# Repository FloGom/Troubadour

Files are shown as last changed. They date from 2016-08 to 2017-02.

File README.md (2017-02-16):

# Troubadour - RetroPie system
Troubadour is a [RetroPie](https://retropie.org.uk/) video game console installed in an old french TV decoder, a [Metronic Zapbox Easy 2](http://www.fnac.com/Metronic-Zapbox-Easy-2/a1663879/w-4) called MZE2 below.

**Fr**   
Troubadour est une console de jeux Rétro utilisant la distribution [RetroPie](https://retropie.org.uk/), et installée dans un ancien décodeur TNT [Metronic Zapbox Easy 2](http://www.fnac.com/Metronic-Zapbox-Easy-2/a1663879/w-4) appelé MZE2 par la suite.
Pour plus d'infos en français voir [LISEZMOI.MD](LISEZMOI.MD)

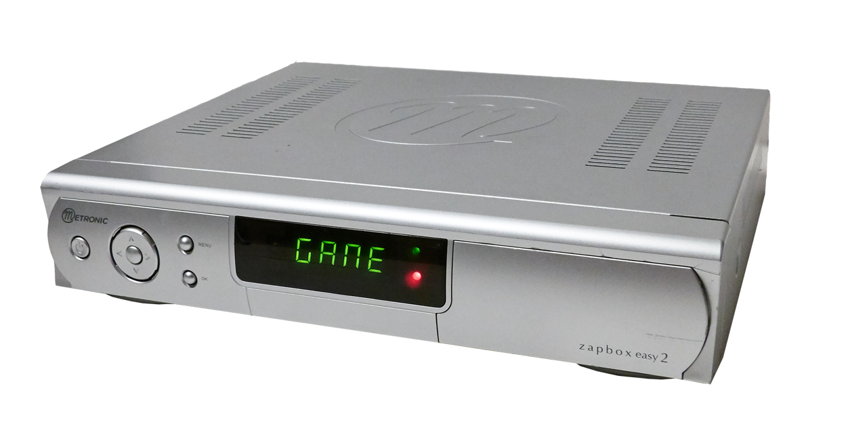
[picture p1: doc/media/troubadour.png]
troubadour


## Updates
* **2016/08/07** - Update the doc.
* **2016/08/02** - Create this repository.

## Features
* Powered with a Raspberry Pi B.
* Power supply from the old TV decoder.
* Original front panel used : volume control, display infos, shutdown button.    See [doc/usage.md](doc/usage.md) for more details.
* Most of the original connectors were used.
* USB power connector (+5V), for small speakers.
* HDMI, Composite compatible : usable on most TV.

Rear panel of Troubadour :
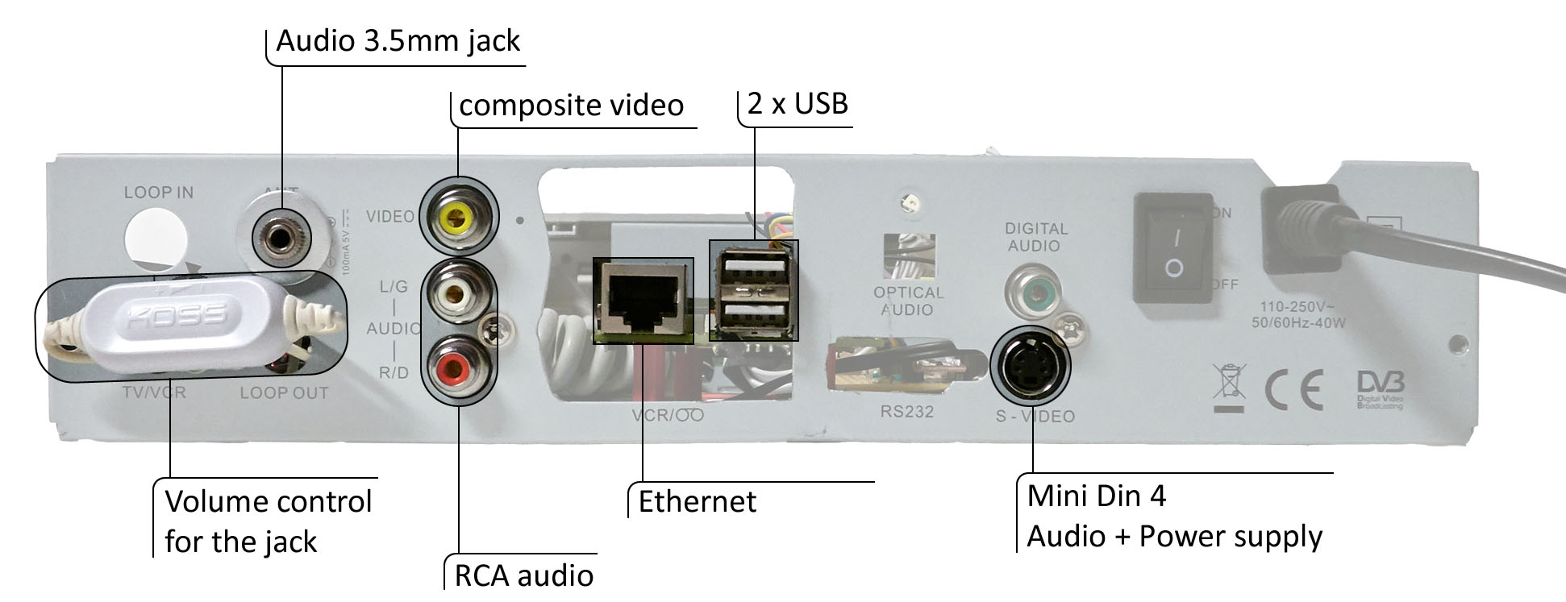
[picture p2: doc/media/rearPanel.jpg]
rear panel


## Build your own

### Internal Wiring
See [doc/wiring.md](doc/wiring.md)

### Volume control script
See [doc/vol_install.md](doc/vol_install.md)

### Build the front panel program
The program is written in C and launch on startup.   
See [doc/build.md](doc/build.md) for further details.

#### Other languages
You can find in the directory *frontPanelProg* the Arduino and python version of the code.   
I maked the Arduino version to test my comprehension of the front panel. The python version is a first attempt to control the front panel with the Raspberry Pi but python is too slow.

### Reverse engineering the front panel
See [doc/frontPanel_hack.md](doc/frontPanel_hack.md).

### Add features to the front panel
You can add more features by editing the frontPanel.c program, see [How To Program the front panel](doc/how_to_program.md) to learn how.

## License
[GNU GPL v3](LICENSE)

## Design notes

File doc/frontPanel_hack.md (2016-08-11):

# Reverse Engineering the front panel

If you want to code new messages or new features for the front panel whithout knowing precisely its design, go to [How To Program the front panel](how_to_program.md)

The front panel can be detached from the case. Using a multimeter and datasheets 
I was able to reverse engineering the front panel :)

You can find the schematics and pinouts [here](../schematics). 
They are made with [Fritzing](http://fritzing.org/home/).

## 1. Wiring of the front panel

### a. The 4 digits, 7-segments display
With the schematics, we can think about the way it works. 
As you can see on the schematics, the polarity is reverse :
* the transistors used are PNP, I made a reminder of their funcioning in the lower left corner for myself. Here they are used as commutators : if the B pin is set LOW, the current pass through the transistor from E to C.
* the 7-segments display is a common anode display. To light up a segment you have to pull LOW the output pin (a, b, c...) and to pull HIGH the anode pin (here *dig1*):   
```
dig1 -------+----->|--- a   
            |
            +----->|--- b
       	    |
            +----->|--- c
            |
            .
            .
            .
            +----->|--- dot point
```    
With a PNP transistor ahead of the anode, the *dig1* must be pull LOW also to light up segments.

### b. 74HC164D chip
This chip is a shift register (serial-in, parallel-out). The bits (LOW or HIGH) sent to the serial pins (DSA and DSB) are shift to the right on each rising edge (LOW to HIGH) on the clock pulse pin.   
More details [here](../schematics/74hc164d.pdf).

The output pins are wired to the cathodes (a, b, c, ...) of the 7-segments display.

So to light up only the **a** segment of the **digit 1** we must do the following :   
* reset the 74hc164d
* set clock pulse pin to LOW
* set the serial pin to LOW
* set clock pulse pin to HIGH
* set the dig1 pin of the display to LOW

To display a "1" we send the following binary code, 0b0110 0000, to the shift register :   

1. We transform 0b0110 0000 into 0b1001 1111 with a XOR because the polarity is reversed : 0b0110 0000 ^ 0b1111 1111 = 0b1001 1111
2. the current bit to send is the LSB (**L**ess **S**ignificant **B**it) : 0b1001 111**1**
3. set clock pulse pin to LOW
4. set the serial pin to the value of the current bit (for the LSB it's HIGH)
5. set clock pulse pin to HIGH
6. we restart from step 2, but this time we take the second bit : 0b1001 11**1**1. And we go on until we reach the MSB (**M**ost **S**ignificant **B**it) 0b**1**001 1111.
7. set the dig1 pin of the display to LOW

### c. buttons
In order to lower the number of output pins for the front panel the buttons are wired to use the shift register.

The buttons are wired that way :
```
            ___        Switches
Serial in -| 7 |-Q0------__---+
  Clock p -| 4 |-Q1------__---|
           | H |-Q2------__---|
           | C |-Q3------__---+--- 7 (output pin)
           | 1 |-Q4------__---|
           | 6 |-Q5------__---|
           | 4 |-Q6------__---|
           |_D_|-Q7------__---+
                              |
                              +----VVVV--- +5V
```

The buttons are normally open and pulled HIGH.

To check if button n°1 *CH+* has been pressed, we use the shift register. The code 0b0111 1111 (reverse polarity : 0 means button pressed, 1 button released) is sent to the shift register, and the state of pin number 7 is checked. If it's LOW the button is pressed, otherwise the button is not pressed :

```
            ___ State  Switches
Serial in -| 7 |-0------------+
  Clock p -| 4 |-1-------__---|
           | H |-1-------__---|
           | C |-1-------__---+--- we read 0 (LOW) on pin 7
           | 1 |-1-------__---|
           | 6 |-1-------__---|
           | 4 |-1-------__---|
           |_D_|-1-------__---+
                              |
                              +----VVVV--- +5V
```

If we pressed another button, we read 1 (HIGH).

See [How To Program the front panel](how_to_program.md) and the source code [frontPanel.c](../frontPanelProg/frontPanel.c) for more details.

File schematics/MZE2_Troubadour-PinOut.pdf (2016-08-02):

Troubadour V1.0 | 02/08/2016

## Troubadour pinouts

### Power supply

### Raspberry Pi B

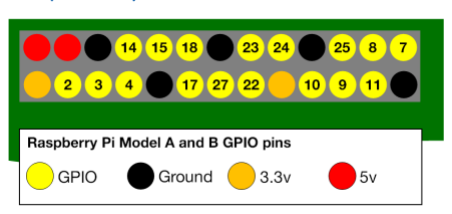
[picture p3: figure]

### Front Panel MZE2

Ratings | Measured
30V | 29,2V
GND
22V | 0V
5V | 4,7V
5V | 4,7V
12V | 12,6V
7V | 0V
GND
3,3V | 3,42V
3,3V | 3,42V
GND
RPi GPIO BCM | MZE2 Front Panel
2 | LED Verte
3 | Serial In
4 | CP
17 | Buttons
22 | Digit 1
23 | Digit 2
24 | Digit 3
25 | Digit 4
1 | 5V
2 | IR LED
3 | Gnd
4 | Green LED
5 | Serial In
6 | CP
7 | Buttons
8 | Gnd
9 | Digit 4
10 | Digit 3
11 | Digit 2
12 | Digit 1

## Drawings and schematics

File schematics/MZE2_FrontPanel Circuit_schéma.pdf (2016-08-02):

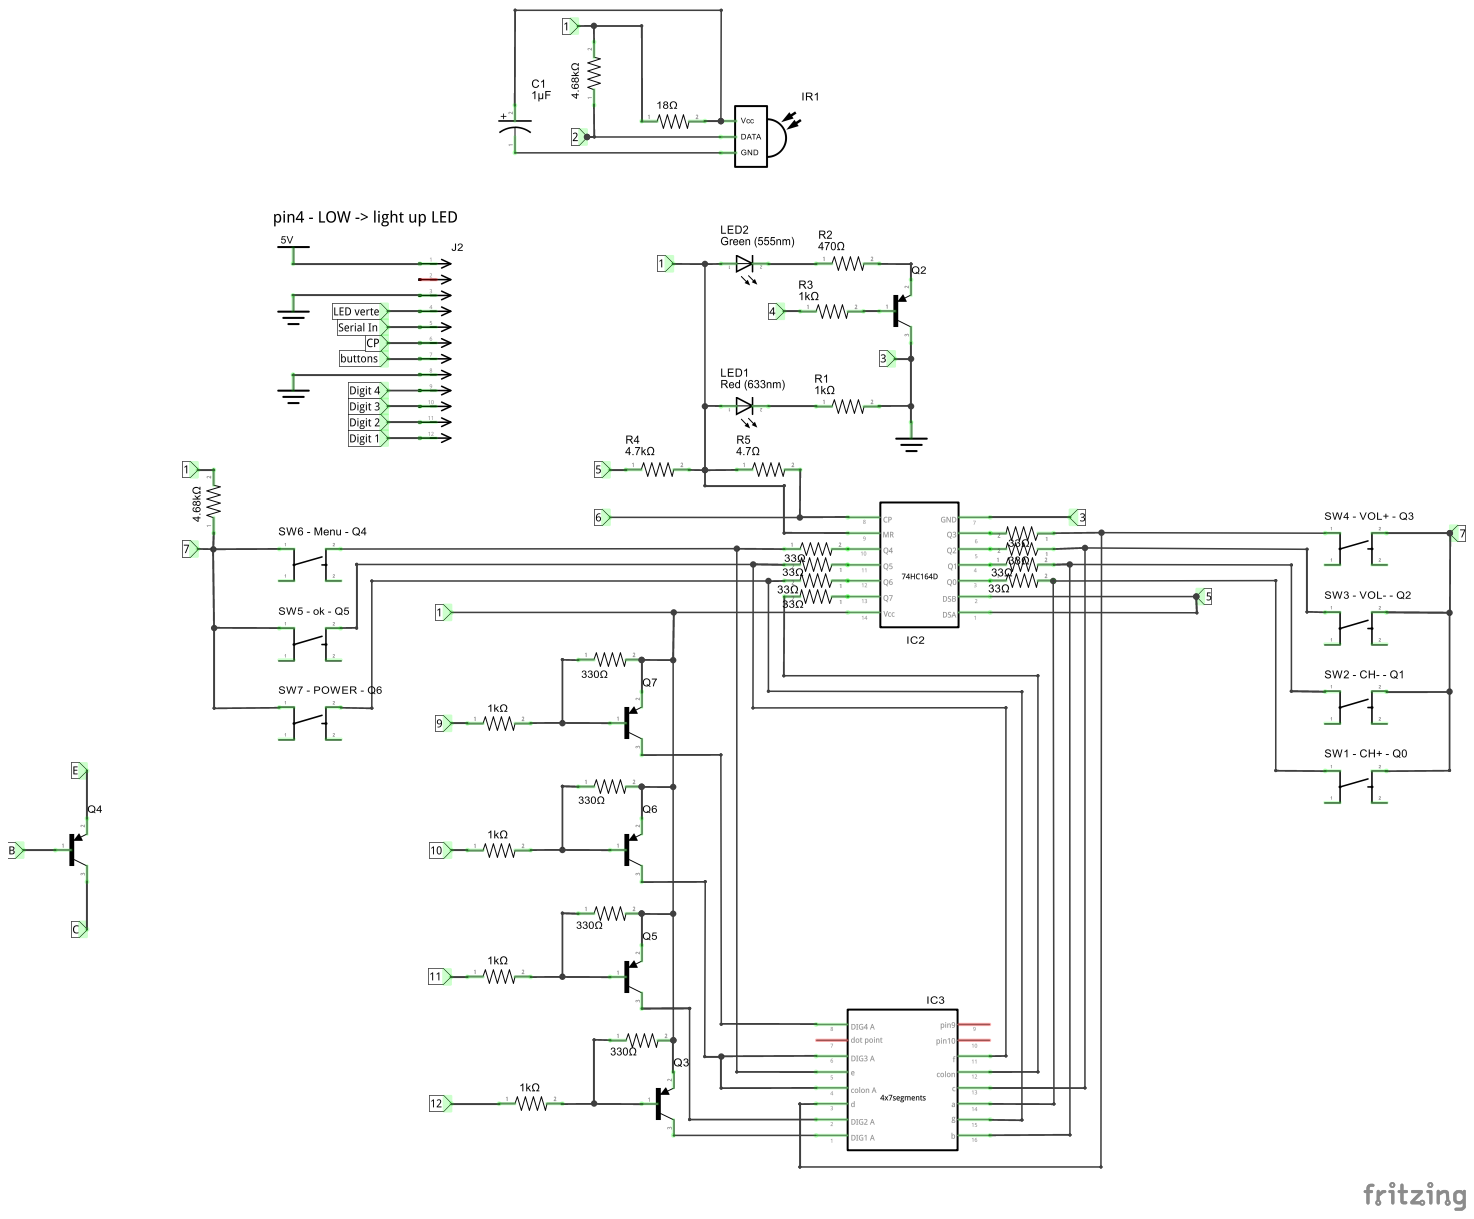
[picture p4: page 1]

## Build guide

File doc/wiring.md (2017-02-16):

# Troubadour Wiring

## Main Parts
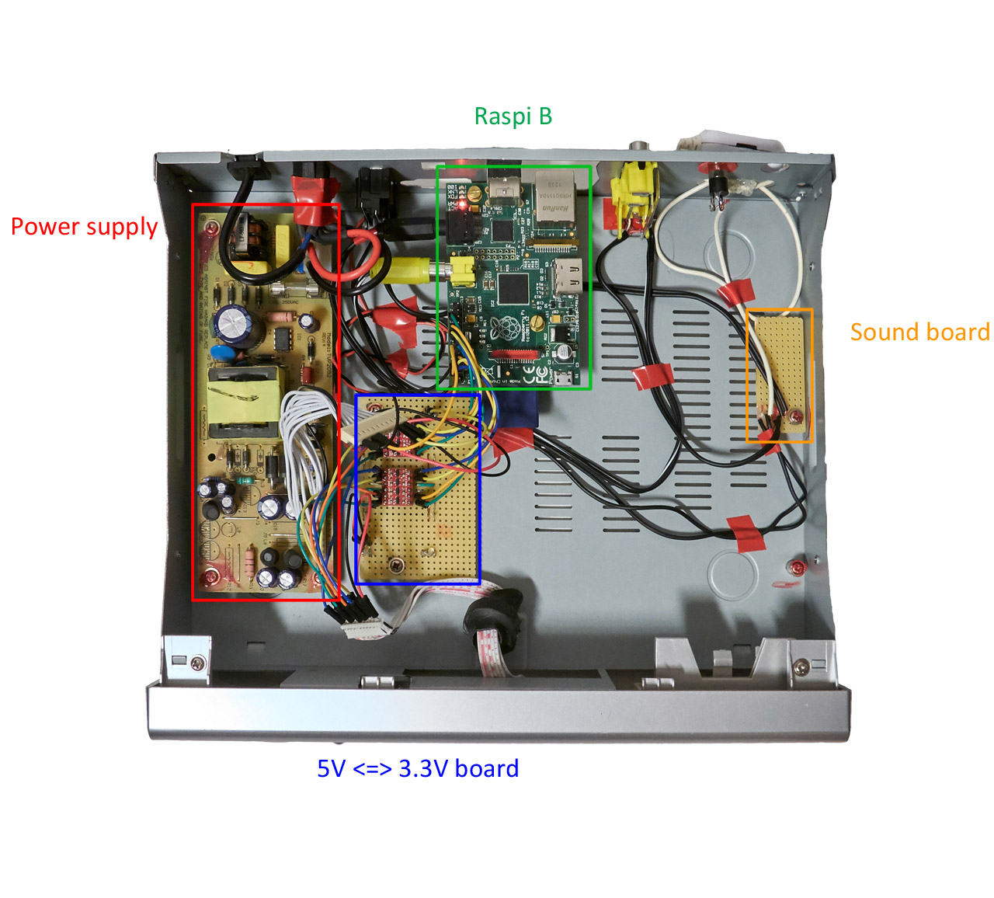
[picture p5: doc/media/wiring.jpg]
inside of Troubadour


I removed the mainboard of the decoder and used the original screw and holes to fix the perfboards.   
For the Raspberry Pi, I did 2 holes in the bottom of the case and fix it using 2 bolts.
The Pi doesn't touch the case thanks to plastic screw anchors.

See [schematics/MZE2_Troubadour-PinOut.pdf](../schematics/MZE2_Troubadour-PinOut.pdf) for 
a precise pin out of each connector.

### 1. Power supply   
It's the original power supply. In this project we use 3.3V and 5V channels.
We plug jumpers directly into the connector.   

IT COULD BE DANGEROUS, SO BE CAREFUL. DO NOT TOUCH COMPONENTS OF THE POWER SUPPLY.  

IF YOU DO NOT KNOW HOW TO DO IT PROPERLY, DO NOT DO IT.   
I DISCLAIM RESPONSIBILITY IF YOU HAPPEN TO BE INJURED, 
OR IF YOU DAMAGE YOUR DEVICES.

### 2. Raspberry Pi B   
The core of the system, he controls the front panel.

### 3. Logic level converter board   
The front panel use 5V logic, and the RPi 3.3V. We used logic level converters 
from sparkfun soldered on a perfboard.

### 4. Sound board   
It's not really a sound board, just a piece of perfboard 
with all the sound wires soldered on it. 
The sound comes from the jack on the Raspberry Pi B then it is distributed
to all the connectors.

## Logic level converter wiring

```
      Front panel       Raspberry Pi B
      connector    -    BCM numbering    -    function
      5V side           3.3V side
	         _____
	  12----|     |----22                  digit 1
	  11----|Level|----23                  digit 2
	  10----|Conv.|----24                  digit 3
	   9----|_____|----25                  digit 4
	         _____
	   4----|     |----2                   Green LED
	   5----|Level|----3                   Serial In
	   6----|Conv.|----4                   Clock Pulse
	   7----|_____|----17                  Buttons
```   

## Desoldering components

For this project the original RCA and composite video connector was desoldered from the motherboard of the MZE2.

A USB female connector was desoldered from an old hub to make a USB power cable. This cable is used to power small extern speakers.

### Advices

It's not easy to desolder components with lot of pins like connectors.

Here are advices from my experience :
* Use a clean soldering iron.
* Heat the component lead and the soldering pad on the motherboard.
* With a desoldering pump, suck melting solder.
* If you do not manage to suck the solder try applying new solder on the old solder. It will help to melt the solder.
* Once the solder is removed try to wiggle the connector with a pair of pliers. 
* If the connector does not come off the motherboard try it again with heating the connector leads. Secure the piece in a clamp before working on it.

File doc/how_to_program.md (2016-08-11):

# How to program the front panel

The program used for the front panel is written in C and the library [wiringPi](http://wiringpi.com/) is used.   

I tried to comment a lot my program in order to help anyone who wants to modify it :)

Do not pay attention to the french comments. It's "personal" comments that help me to learn C.

## How to add messages
Look for the following line, near #90 :
```c
char messages[NUMITEMS][5] =
```
Add your message at the end, no more than 4 characters and no space for the moment.   
Don't forget to change the number of items in the constant `NUMITEMS` just above.

## How to add features when a button is pressed
Button `OK` (5) and `MENU` (6) are not used, so you can add features.

To do this edit the portion of code below the second `switch(myButton){`, add `case 5:` and `case 6:`.

### Mini case-study : a mini-game
If you want for example add a mini game on the 4 digit display when you press the `MENU` button you can do this as follow :
* When button #6 is pressed put 2 in `evenement` variable.
* In the first switch create the `case 2:` and put your code here for the mini game.
Your game can use any of the button while you are in this evenment, even those previously used.
* Don't forget to use one of them to quit the game.

## Wiring of buttons
The integers returned by the function `zpe2buttons` are like below :
```
                               buttons number
        ^       MENU    |            1       6 
 o    <   >             |     7    3   4  
        v       OK      |            2       5 
```

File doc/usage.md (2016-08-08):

# Troubadour Front Panel usage

## The front panel

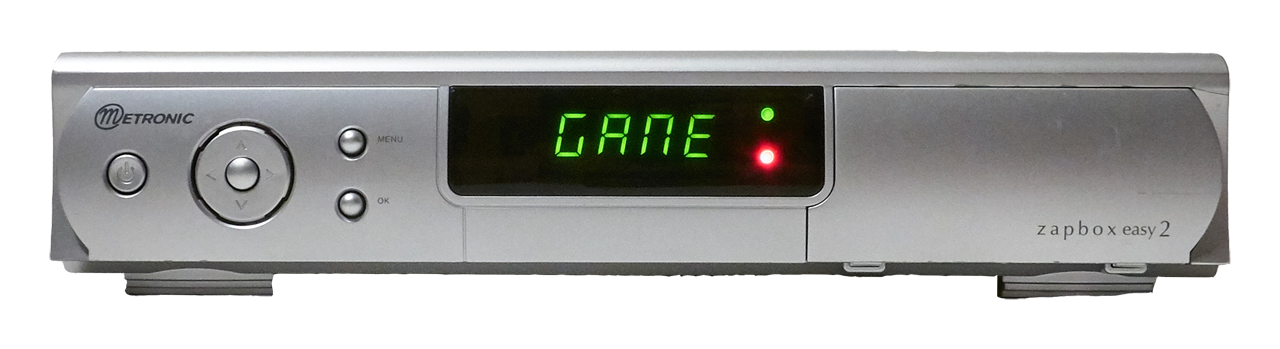
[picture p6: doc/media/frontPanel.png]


## Buttons
There are 7 push buttons on the front panel :

### 1. The Power button

You can properly shut down the system by pressing once on the **power** button. 
The message *quit* appears on the screen, inviting you to confirm with **OK** or cancel with **MENU**.

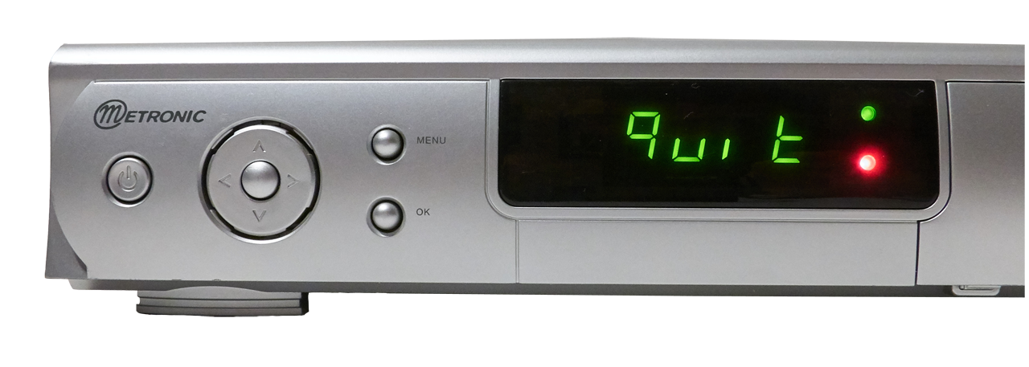
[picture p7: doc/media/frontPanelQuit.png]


### 2. Control the audio volume

With `^`and `v` buttons you can increase or decrease the volume. Be sure to have the `vol`script installed.   
See [vol_install.md](vol_install.md) for more details.   
The screen go black for less than a second each time these buttons are pressed, it's normal. 
The script is quiet slow to change the volume.

### 3. Display messages and info

With `<` and `>` you can display different information.   
By default the following messages will appears :
* GAME
* 1984
* 00:02  =>  The time *(hh:mm)* since the start of the system.   

If you want to add your messages or new functions see [How To Program the front panel](doc/how_to_program.md).

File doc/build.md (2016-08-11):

# Build the front panel program
The program is build directly onto the RPi. 
This guide assumes you have a RPi install with the [RetroPie](https://retropie.org.uk/) distribution.

## Download and install

### 1. Install tools   

* The program uses [wiringPi](http://wiringpi.com).   
[Download an install](http://wiringpi.com/download-and-install/) it from sources.

### 2. Download the sources

* If you are familiar with git tools you are recommended to use it :   
`git clone https://github.com/FloGom/Troubadour.git`

* But you can also download zip archive from :   
https://github.com/FloGom/Troubadour/archive/master.zip

## Build Program

1. open terminal window.
2. move to project directory :   
`cd Troubadour/frontPanelProg`

3. compile the program :   
`gcc frontPanel.c -o frontPanel -l wiringPi`   
If the command returns nothing it's Ok. If the command returns error(s), 
search on Internet by typing it in google or better [stackoverflow](http://stackoverflow.com/).

4. test the program, launch it with :   
`sudo ./frontPanel`    
(assuming you're always in frontPanelProg directory).   
Normally you should see something like this :   
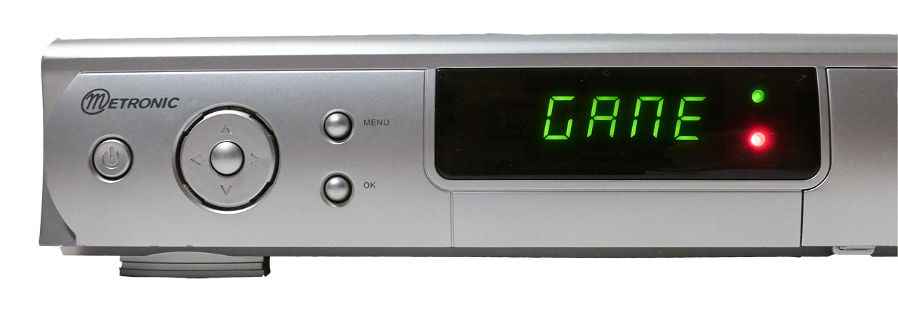
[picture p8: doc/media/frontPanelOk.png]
If you are able to read GAME everything is good!
   
5. to launch the programm on startup before any users have logged in, you need to edit `/etc/rc.local` :   
`sudo nano /etc/rc.local`   
add the following line after the commented lines (the lines beginning with #) :   
`sudo /home/pi/Troubadour/frontPanelProg/frontPanel &`   
*The `&` means that the program will run in background.*
6. Restart your RPi, you should now see *GAME* appears on the front panel after the RetroPie splashscreen.

## Usage of the front panel

See [usage.md](usage.md) to know more about the use of the front panel.

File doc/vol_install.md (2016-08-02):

# Volume script install

## Install
1. Copy the file *vol* in [Troubadour/frontPanelProg](../frontPanelProg) in `/usr/local/bin/`
2. Make it executable :   
`sudo chmod a+x /usr/local/bin/vol`
3. Test it by typing :   
`vol` in a terminal, this command outputs the current volume as a number between 0 and 100

## Sources
If you have problem getting the script work, go to http://www.dronkert.net/rpi/vol.html

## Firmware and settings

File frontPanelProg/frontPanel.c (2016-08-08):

#include <stdio.h>
#include <string.h>
#include <time.h>
#include <wiringPi.h>

// Pin number declaration using Broadcom chip pin numbers
const int greenLED = 2;
const int serial = 3;	// data pin
const int cp = 4;	// clock pulse, chip on the front panel shifts right bits on rising edge
const int buttons = 17;

// the first pin for the digits, the 3 others wil be dig1 + 1, dig + 2 and dig + 3
const int dig1 = 22;

// list of character
unsigned char listChar [] = {
0b11111100, // 0
0b01100000, // 1
0b11011010, // 2
0b11110010, // 3
0b01100110, // 4
0b10110110, // 5
0b10111110, // 6
0b11100000, // 7
0b11111110, // 8
0b11110110, // 9
0b11101110, // A
0b00111110, // b
0b10011100, // C
0b01111010, // d
0b10011110, // E
0b10001110, // F
0b10111100, // G
0b00101110, // h
0b00001000, // i
0b01111000, // J
0b00101110, // k=h
0b00001100, // l = 1
0b11101100, // M = PI
0b00101010, // n
0b00111010, // o
0b11001110, // P
0b11100110, // q
0b00001010, // r
0b10110110, // S = 5
0b00011110, // t
0b00111000, // u
0b00111000, // v = u
0b01111100, // W = U
0b01101110, // X = H
0b01110110, // Y
0b11011010  // Z = 2
};

// declaration of functions
void zpe2write(unsigned char octet);
void zpe2println(char *word, char start);
void zpe2println_colon(char *word, char start, int _colon);
//void zpe2reset(void);
int zpe2buttons(void);

int minutes(double _startTime, double _endTime);
int hours(int minutes);

int main(void){
    // ===== SET UP ===== //
    // set up broadcom pin numbering system
    wiringPiSetupGpio();

    pinMode(greenLED, OUTPUT);
    pinMode(serial, OUTPUT);
    pinMode(cp, OUTPUT);
    pinMode(buttons, INPUT);
    // to avoid the error 'for' loop initial declarations are only allowed in mode C11 and C99
    int i;
    for(i=0; i<4; i++){
        pinMode(dig1 + i, OUTPUT);
        // by default digit LEDs are turned off
        digitalWrite(dig1 + i, 1);
    }

    time_t startTime, nowTime;
    startTime = time(NULL);


    char mot[] = "game";
    // constante pour éviter des problèmes d'initialisation
    #define NUMITEMS 3
    //                             0       1       2     3
    char messages[NUMITEMS][5] = {"game", "1984", "time"};
    int currentMsg = 0;

    char command[50];

    int myButton = 0;
    int oldButton = 0;
    int evenement = 0;

    int minutesPlayed;
    int hoursPlayed;

    // ===== LOOP =====
    while(1){
        nowTime = time(NULL);

        // playing time calculation
        minutesPlayed = minutes(startTime, nowTime);
        hoursPlayed = hours(minutesPlayed);
        minutesPlayed = minutesPlayed - hoursPlayed*60;
        // fait planter le programme si on déclare char *messages[3] = { ... } en ligne 90
        sprintf(messages[2], "%02d%02d", hoursPlayed, minutesPlayed);
        
        // choose to print colon or not
        if(currentMsg==2){
            zpe2println_colon(mot, 0);
        }else{
            zpe2println(mot, 0);
        }

        // handle buttons events
        myButton = zpe2buttons();
        switch(evenement){
            // no button has been pressed before
            case 0: switch(myButton){
                        case 0: strcpy(mot, messages[currentMsg]);
                                break;
                        // button '^' has been pressed
                        case 1: strcpy(command, "vol +");
                                system(command);
                                break;
                        // button 'v' has been pressed
                        case 2: strcpy(command, "vol -");
                                system(command);
                                break;
                        // button '<' has been pressed
                        case 3: if(myButton != oldButton){
                        		// display previous msg
                                    currentMsg--;
                                }
                                if (currentMsg < 0){
                                    currentMsg = NUMITEMS - 1;
                                }
                                break;
                        // button '>' has been pressed
                        case 4: if(myButton != oldButton){
                        		// display previous msg
                                    currentMsg++;
                                }
                                if(currentMsg > NUMITEMS - 1){
                                    currentMsg = 0;
                                }
                                break;
                        // button power has been pressed
                        case 7: strcpy(mot, "quit");
                                // go back home to avoid colon on quit when playing time is selected before
                                currentMsg = 0;
                                evenement = 1;
                                break;
                        default: //memset(mot, myButton + '0', 4); // show button number
                                //mot[0] = mot[1] = mot[2] = mot[3]; // char considérés pas modifiables
                                break;
                        }

                    oldButton = myButton;
                   
                    break;
            // power button has been pressed in the previous loop
            case 1: if(myButton == 5){ // confirm button 'ok'
                        strcpy(command, "sudo halt");
                        system(command);
                    }else if(myButton == 6){ // cancel the action 'menu'
                        evenement = 0;
                    }
                    break;
            default: 
                    break;
        }
    }
    return 0;
}


void zpe2write(unsigned char octet){
    //write a byte to the front panel chip
    unsigned char word = octet;
    int i;
    for(i = 0; i<8; i++){
        digitalWrite(cp, 0);
	// polarity is reverse, a XOR mask is used to reversed it
        unsigned char lsb = (word ^ 0b11111111) & 0b00000001;
        digitalWrite(serial, lsb);
        word = word >> 1;
	// clock pulse to shift right the bit
        digitalWrite(cp, 1);
    }
}

void zpe2println(char *word, char start){
    // print a full line of text during very small time
    int i, ordChar;
    // si char ordChar on a en sortie 218, 226, ... pas du tout ce qu'on attend, vérif' codage des nombres
    // '1' = 49
    // - 'a' = -97
    // 49 - 97 = -38 => -38 +256 = 218 => bouclé

    for(i = 0; i < 4; i++){
        ordChar = word[i] - 'a' + 10;
        //printf("%i\n",ordChar);
        //delay(2000);
        if(ordChar < 0){
            ordChar = ordChar + 39;
            //printf("%i\n",ordChar);
            //delay(2000);
        }
    zpe2write(listChar[ordChar]);
    // light up the digit (reverse polarity)
    digitalWrite(dig1 + i, 0);
    // make a small pause in order to see the msg
    delay(1);
    digitalWrite(dig1 + i, 1);
    }
}

void zpe2println_colon(char *word, char start){
    // print a full line of text during very small time but with a colon
    int i, ordChar;
    // si char ordChar on a en sortie 218, 226, ... pas du tout ce qu'on attend, vérif' codage des nombres
    // '1' = 49
    // - 'a' = -97
    // 49 - 97 = -38 => -38 +256 = 218 => bouclé
    for(i = 0; i < 4; i++){
        ordChar = word[i] - 'a' + 10;
        //printf("%i\n",ordChar);
        //delay(2000);
        if(ordChar < 0){
            ordChar = ordChar + 39;
            //printf("%i\n",ordChar);
            //delay(2000);
        }
        if( i == 2){
            zpe2write(listChar[ordChar] + 1);
            //last bit of 3rd digit (number 2) is for the colon
        }else{
            zpe2write(listChar[ordChar]);
        }
        // light up the digit (reverse polarity)
        digitalWrite(dig1 + i, 0);
        delay(2);
        digitalWrite(dig1 + i, 1);
    }
}

// to reset a digit we can also turn off the digit...
// useless
/*
void zpe2resetDigit(void){
    // reset all digit
    digitalWrite(serial, 1);
    int i;
    for(i = 0; i<9; i++){
        digitalWrite(cp, 0);
        digitalWrite(cp, 1);
    }
}
*/

int zpe2buttons(void){
    // return the number of the pressed button, see schematic for more details
    int i;
    int buttonPressed = 0;
    // buttons order
    int listButtons [7] = {1, 2, 3, 4, 6, 5, 7};
    // we put 0 in Q0 because the buttons are normally HIGH
    // the polarity is reversed so we send :
    zpe2write(0b10000000);
    // after the zpe2write function the buffer looks like this :
    // Q0 Q1 Q2 Q3 Q4 Q5 Q6 Q7
    //  0  1  1  1  1  1  1  1
    digitalWrite(serial, 1);
    for( i=0; i<7; i++){
        digitalWrite(cp, 0);
        // when the button is pressed the pin is LOW, see schematics for more details
        if(!digitalRead(buttons)){
            buttonPressed = listButtons[i];
        }
        digitalWrite(cp, 1);
    }
    return buttonPressed;
}

// notes
// scrolling text
// int compteur = zpe2println(char *word, int compteur)
// pas malin pour gérer le temps (variable globale)
// on utilise zpe2println()
// on joue avec start
// récup la longueur du texte =>calcul
// => liste avec les longueurs (pas automatique)

int minutes(double _startTime, double _endTime){
    return((int)(_endTime - _startTime)/60);
}

int hours(int minutes){
    return((int)(minutes/60));
}

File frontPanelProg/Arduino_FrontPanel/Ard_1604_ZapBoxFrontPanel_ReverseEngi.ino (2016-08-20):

#include <IRremote.h>
#include <IRremoteInt.h>
// https://github.com/z3t0/Arduino-IRremote
// http://www.sbprojects.com/knowledge/ir/index.php
/* ZapBox Easy 2 - front panel - reverse engineering

    Florentin SALOMEZ - 13 Juillet 2016
*/
// IR Libraries

// on envoie le LSB d'abord
//            x Q0 Q1 Q2 Q3 Q4 Q5 Q6 Q7
byte nombre =  B00110000;  // écrire un 1
byte masque =  B00000001;
byte nbWrite = B00000000;
byte listNombres [10]= {
  B1111110,
  B0110000,
  B1101101,
  B1111001,
  B0110011,
  B1011011,
  B1011111,
  B1110000,
  B1111111,
  B1111101
};

byte button = B00000000;

void setup() {

  // pin for each digit
  // set HIGH in order to disabled each one
  for(byte i = 8; i<12; i++){
   pinMode(i, OUTPUT);
   digitalWrite(i, HIGH); 
  }

  pinMode(3, INPUT);  // boutons
  
  pinMode(4, OUTPUT); // LED verte
  digitalWrite(4, HIGH);
  pinMode(5, OUTPUT); // serial in
  pinMode(6, OUTPUT); // clock signal
  digitalWrite(6, LOW);

  digitalWrite(8, LOW);

  for (byte i = 0; i < 7; i++) {
    digitalWrite(6, LOW);
    //delay(500);
    nbWrite = (nombre ^ B11111111) & masque;
    digitalWrite(5, nbWrite);
    nombre = nombre >> 1;
    digitalWrite(6, HIGH);

  }

  digitalWrite(4,LOW); //ligth up the green led
  
  delay(1000);
  nombre = B1101101;
  for (byte i = 0; i < 7; i++) {
    digitalWrite(6, LOW);
    //delay(500);
    nbWrite = (nombre ^ B11111111) & masque;
    digitalWrite(5, nbWrite);
    nombre = nombre >> 1;
    digitalWrite(6, HIGH);
  }

  delay(1000);
  zpe2PrintDigit(3);

  digitalWrite(8, HIGH);
}

byte compteur = 0;


void loop() {
  // we send the bits
  zpe2PrintDigit(button);
  // we activate one digit
  digitalWrite(8 + compteur%4, LOW);
  //make a pause of some ms in order to see the light of the LED
  delay(1);
  // we deactivate the digit
  digitalWrite(8 + compteur%4, HIGH);
  compteur++;

  //test for button pressed
  button = zpe2Button();
}


void zpe2PrintDigit(byte nb){
  zpe2Write(listNombres[nb]);
}

void zpe2Write(byte _word){
  byte nombre = _word;
  for (byte i = 0; i < 7; i++) {
    digitalWrite(6, LOW);
    //delay(500);
    // with ^ (XOR) we change 0 to 1 and 1 to 0
    // with a mask B0000 0001 we keep the last bit
    nbWrite = (nombre ^ B11111111) & masque;
    digitalWrite(5, nbWrite);
    nombre = nombre >> 1;
    digitalWrite(6, HIGH);
  }
}

byte zpe2Button(){
  byte buttonPressed = 0;
  // buttons order
  byte buttons[7]= {1, 2, 3, 4, 6, 5, 7};
  // on met un 1 dans Q0
  zpe2Write(B01111111);
  digitalWrite(5, HIGH);
  // on mesure la broche 7 
  for(byte i = 0; i<7; i++){
    // set the clock pin to LOW
    digitalWrite(6, LOW);
    // if a button is pressed
    if(!digitalRead(3)){
      buttonPressed = buttons[i];
    }
    // set the clock pin to HIGH, doing so make the 1 to shift right
    digitalWrite(6, HIGH);
  }
  return buttonPressed;
}
